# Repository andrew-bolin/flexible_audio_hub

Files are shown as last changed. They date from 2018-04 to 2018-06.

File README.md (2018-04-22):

# flexible_audio_hub

## The Challenge

My ears and speakers will last a lifetime (I hope), but home theatre audio standards do not. My old stereo amplifier works fine, why can't I get an HDMI upgrade module that gives it CEC (control via TV remote). If I buy a 5.1 channel amplifier, why do I have to throw it in the bin to upgrade to Atmos?

A modern AVR (Audio-Video Receiver) is a fantastic piece of technology, but they are available only in certain fixed configurations and are not easily modifiable.

## How Will We Alleviate The Problem?

1. A modular "hub" that allows incremental upgrades, e.g. an extra analog input, an extra two channels of amplification, or even another hub...
2. Compatibility with other open source projects in this field.
3. Ability to make use of readily available (cheap!) modules from China.
4. Ability to connect to home automation systems (e.g. limit the volume and turn off the subwoofer if someone's in bed, or play your wake-up alarm at rock concert levels throughout the house)

The modular system will be entirely open-source so that any interested person can make their own module to serve their unique needs (or for fun). Eventually I would like to see compatible modules available from multiple vendors (much like Raspberry Pi & Arduino add-ons).

## (Notes Working Towards) The Specification

[The Current Specification](SPECIFICATION.md) - very much a work in progress!

The first stage will be electrical & communications protocol only.

Currently, I am deciding on a connector - if anyone knows a connector that is a reasonable pitch (0.5 - 2.5mm), keyed, upwards-compatible with extra pins (e.g. a 16-pin plug can fit into a 20-pin socket), and **cheap**, please get in contact!

*Previously, I started a similar project using a backplane, because edge connectors are cheap, but the design I was using had the switching complexity by necessity in every module, was difficult to integrate into a chassis, and did not offer full flexibility for multiple simultaneous outputs. Now I will move that complexity to a "hub" board.*

Each module should (yes, it's optional) have an ID EEPROM & accept a few basic commands (Enable, select channel) via I2C. This can be achieved via a PCA9500 I/O expander or ATtiny, for example. Modules without the ID/Control interface will require more configuration effort and might waste a bit more power (the central hub will probably not have power switches per module).

The hub will be controlled by I2C, and a C++ library will be provided that will be usable via Arduino and Raspberry Pi. The hub will be able to be daisy-chained. 

----

These files are distributed under The TAPR Open Hardware License, version 1.0.  
See LICENSE.txt or https://www.tapr.org/ohl.html

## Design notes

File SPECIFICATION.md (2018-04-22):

# Flexible Audio Hub - Specification

## PRELIMINARY - FOR COMMENT - NOT FOR MANUFACTURE

# Hub Connector
Equivalent to [FreeDSP expansion connector](https://github.com/freeDSP/WIKI-AND-GENERAL-TOPICS/wiki/freeDSP-Guidelines).
16 pin (2x8) header, 2.54mm pitch.

## Hub-side

| Function | Pin | Pin | Function |
| ---: | :---: | :---: | --- |
| +12V |  1|2 | Gnd |
| I2S in |  3|4 | Gnd |
| I2S out|  5|6 | Gnd |
| bit clk|  7|8 | Gnd |
| LR clk |  9|10| Gnd |
| SDA | 11|12| Gnd |
| SCL | 13|14| Gnd |
| Mclk | 15|16| Gnd |

## Module-side

Out & in are swapped from hub side.

| Function | Pin | Pin | Function |
| ---: | :---: | :---: | --- |
| +12V |  1|2 | Gnd |
| **I2S out**|  3|4 | Gnd |
| **I2S in** |  5|6 | Gnd |
| bit clk|  7|8 | Gnd |
| LR clk |  9|10| Gnd |
| SDA | 11|12| Gnd |
| SCL | 13|14| Gnd |
| Mclk | 15|16| Gnd |

# Hub ID EEPROM

I2C Interface, address 0x50 (7 bit address) / 0xA0  (8 bit address).  
16 bit addressing. Any standard EEPROM chip should do the trick - CAT24Cxx, AT24Cxx, AT24CSxx, etc.

## Memory Map	 - Development version 1

Protocol / EEPROM uses odd version numbers for development, even numbers for production. Zero is not a valid version.
Strings are ASCII (maybe unicode later...).
This version needs only 1kbit of memory.

| Byte | Function | Detail |
| ---: | --- | --- |
| 0 | Magic Number | 0x46 'F' |
| 1 | Magic Number | 0x41 'A' |
| 2 | Magic Number | 0x48 'H' |
| 3 | Magic Number | 0x00 ''  |
| 4 | Bus Protocol Version | 0x01 |
| 5 | Module type | bitfield - in,dsp,out, etc |
| 6 | Number of audio channels in I2S data | only 0x02 for now |
| 7 | Number of selectable module channels | e.g. if we have multiple stereo ADCs |
| 8 | Power requirement | rated mA from 12V supply |
| 8-15 | -- Reserved -- | |
| 16-31| Module short name | 16 characters - model number or similar |
| 32-95| Module long name | 64 characters - e.g. "Quad Stereo Balanced Analog Input"|
| 96-127|Manufacturer | 32 characters |
|128-255| -- Reserved -- | |
|256+ | User Configuration (Module defined) ||

# Module Control

Modules can optionally be controlled by I2C commands.
Address 0x20 (7 bit address) / 0x40 (8 bit address), for compatibility with [PCA9500](https://www.nxp.com/docs/en/data-sheet/PCA9500.pdf). I2C Command is per PCA9500 output control (will add detail here later).

## Proposed Commands
* Select 0 (select an input/output/mode)
* Select 1
* Select 2
* Select 3
* Power
* Mute

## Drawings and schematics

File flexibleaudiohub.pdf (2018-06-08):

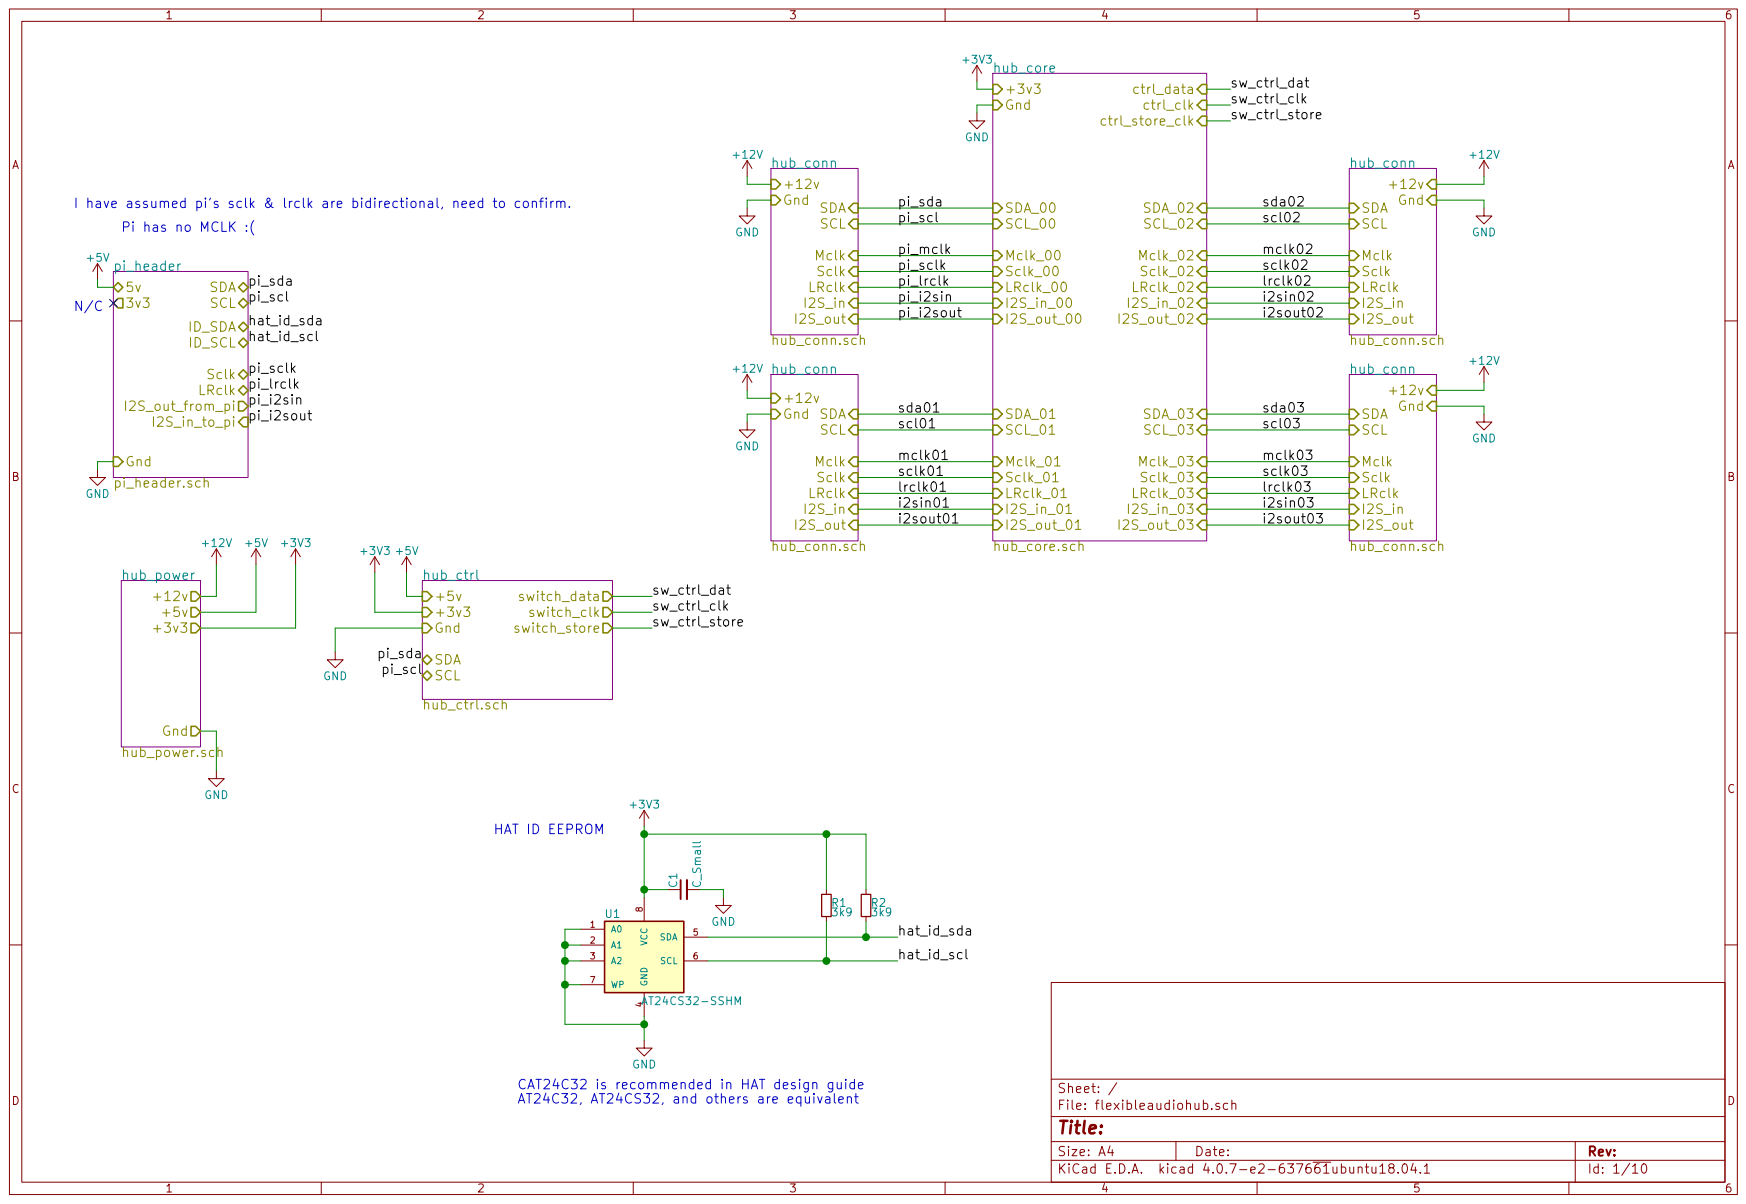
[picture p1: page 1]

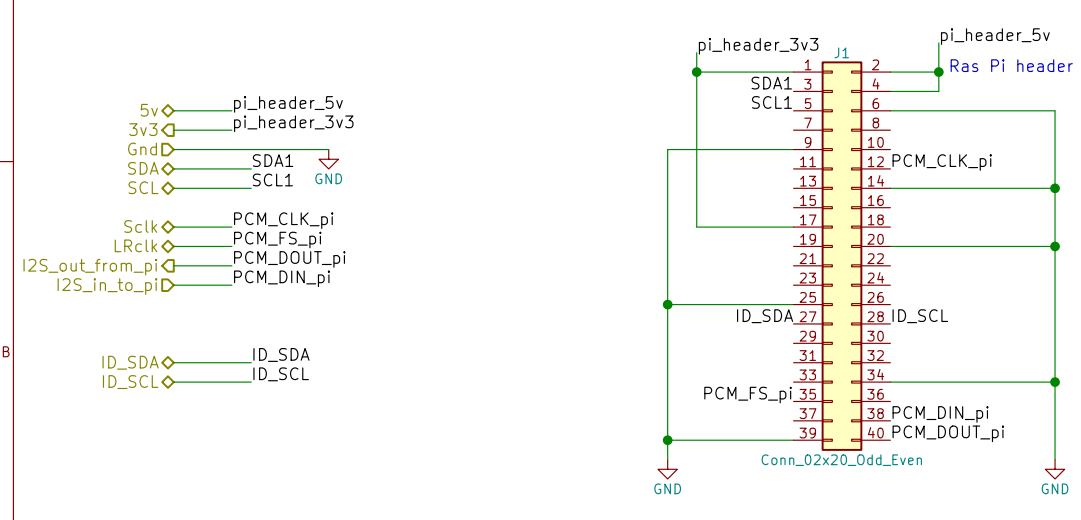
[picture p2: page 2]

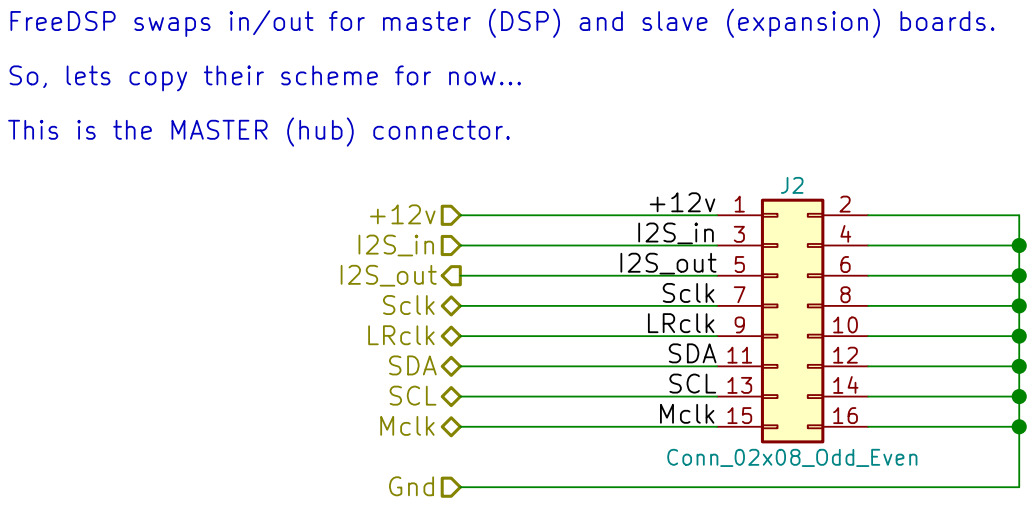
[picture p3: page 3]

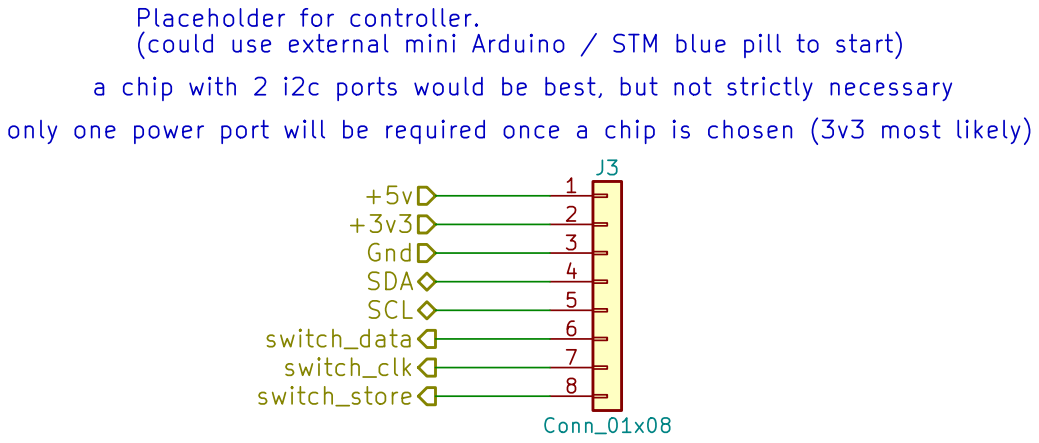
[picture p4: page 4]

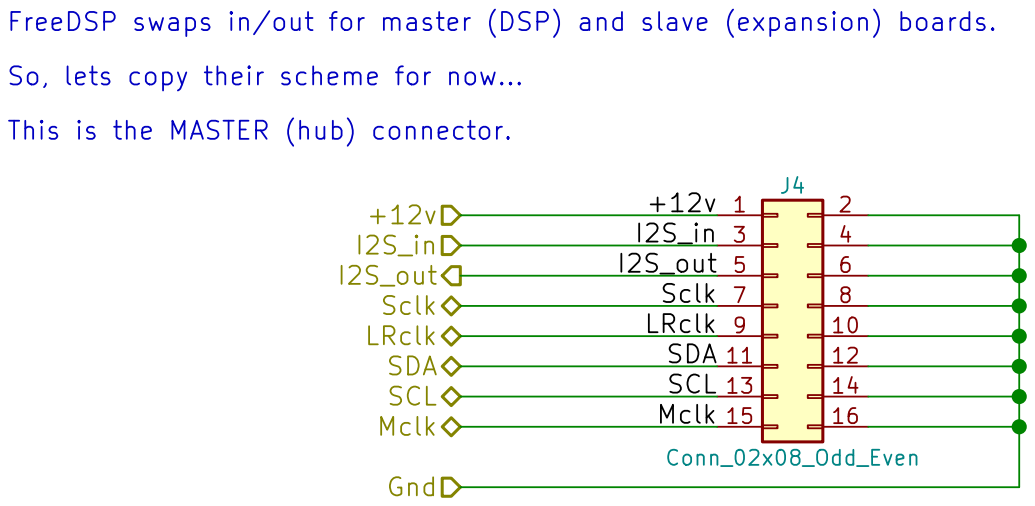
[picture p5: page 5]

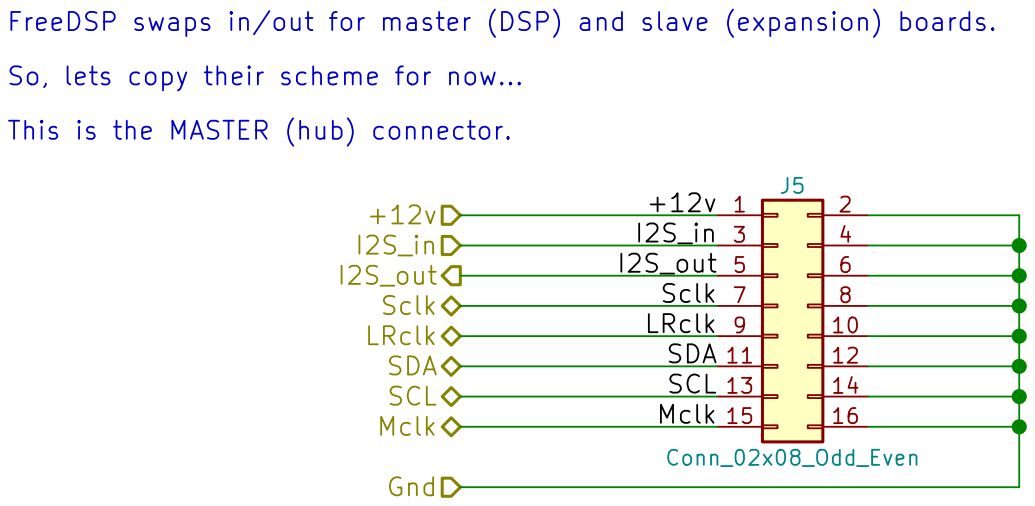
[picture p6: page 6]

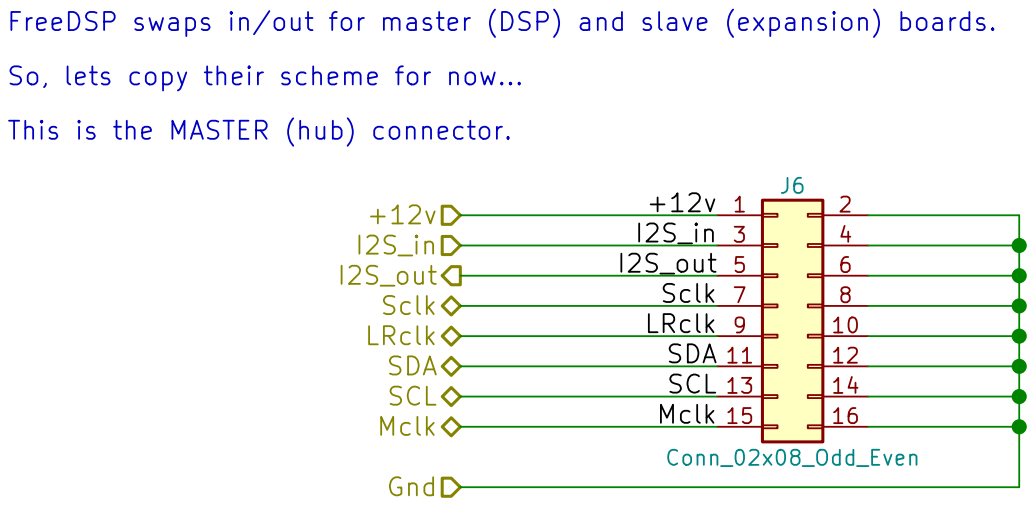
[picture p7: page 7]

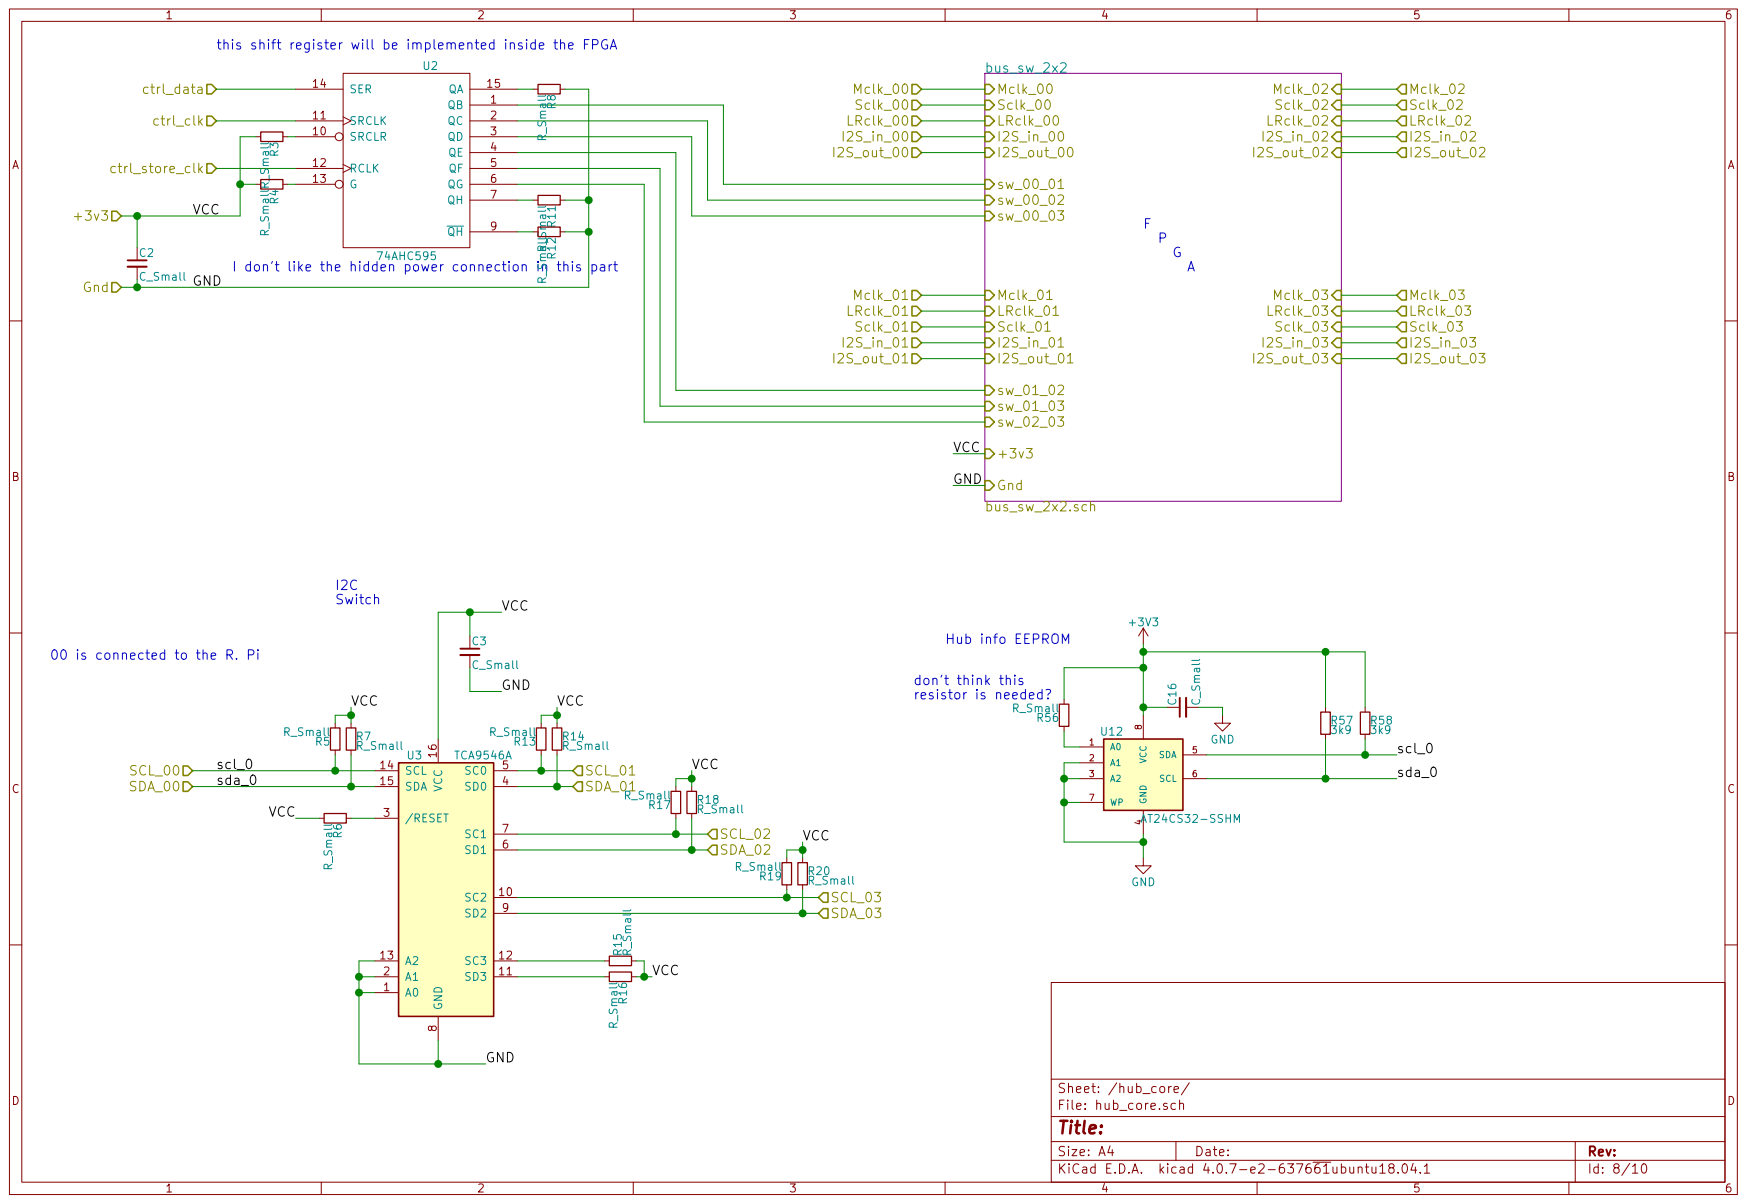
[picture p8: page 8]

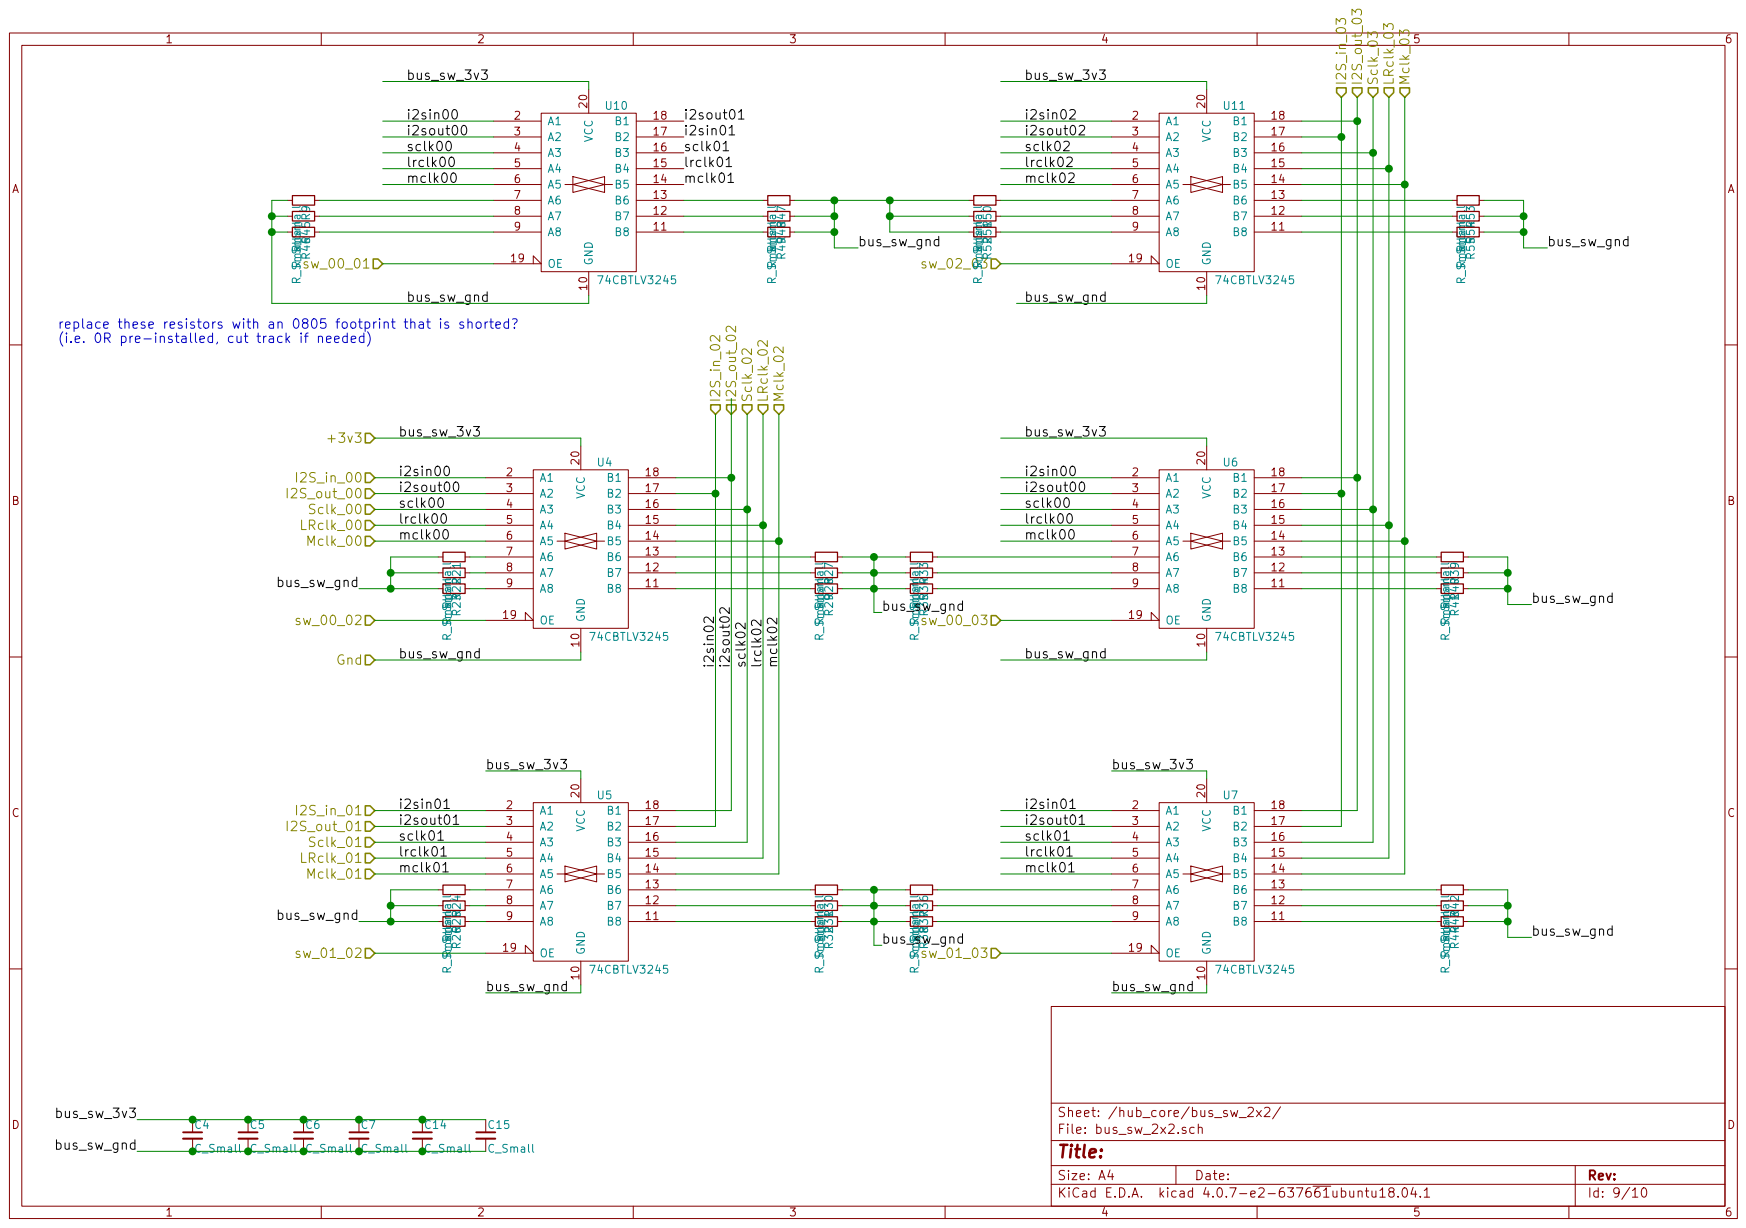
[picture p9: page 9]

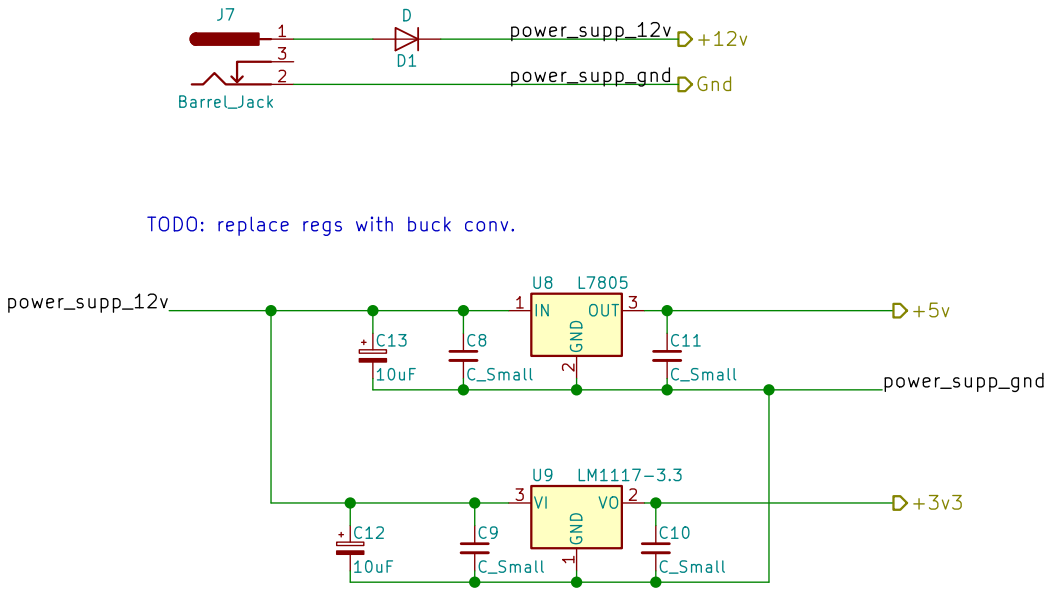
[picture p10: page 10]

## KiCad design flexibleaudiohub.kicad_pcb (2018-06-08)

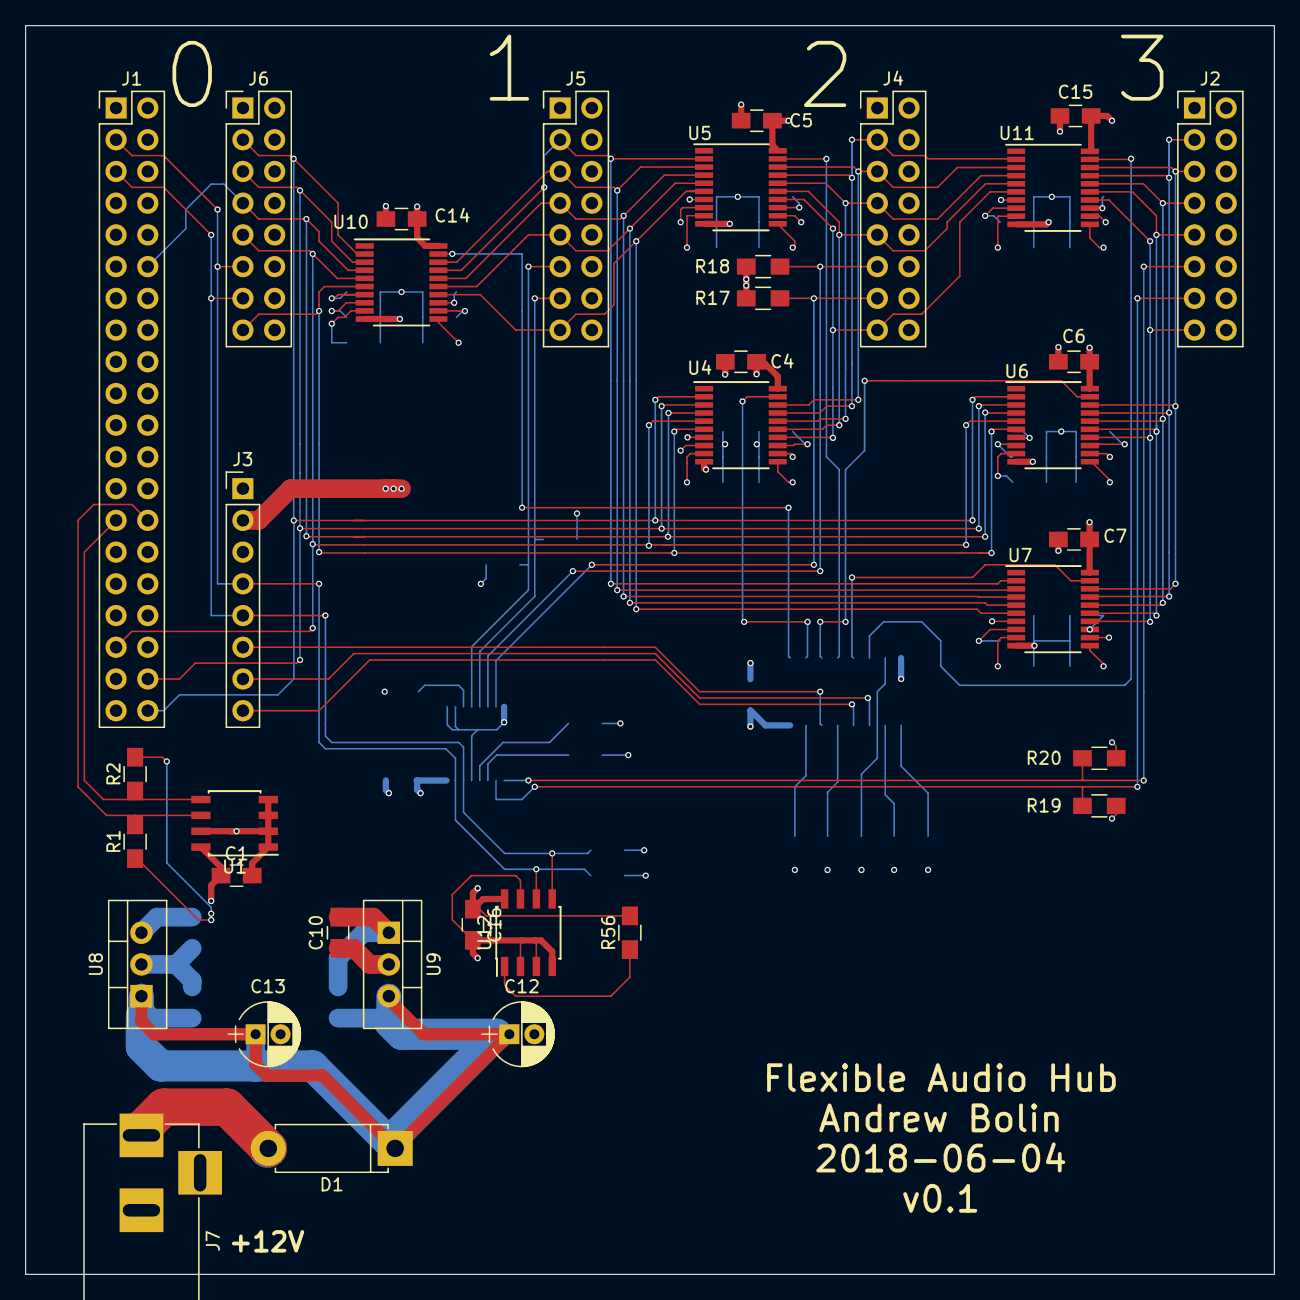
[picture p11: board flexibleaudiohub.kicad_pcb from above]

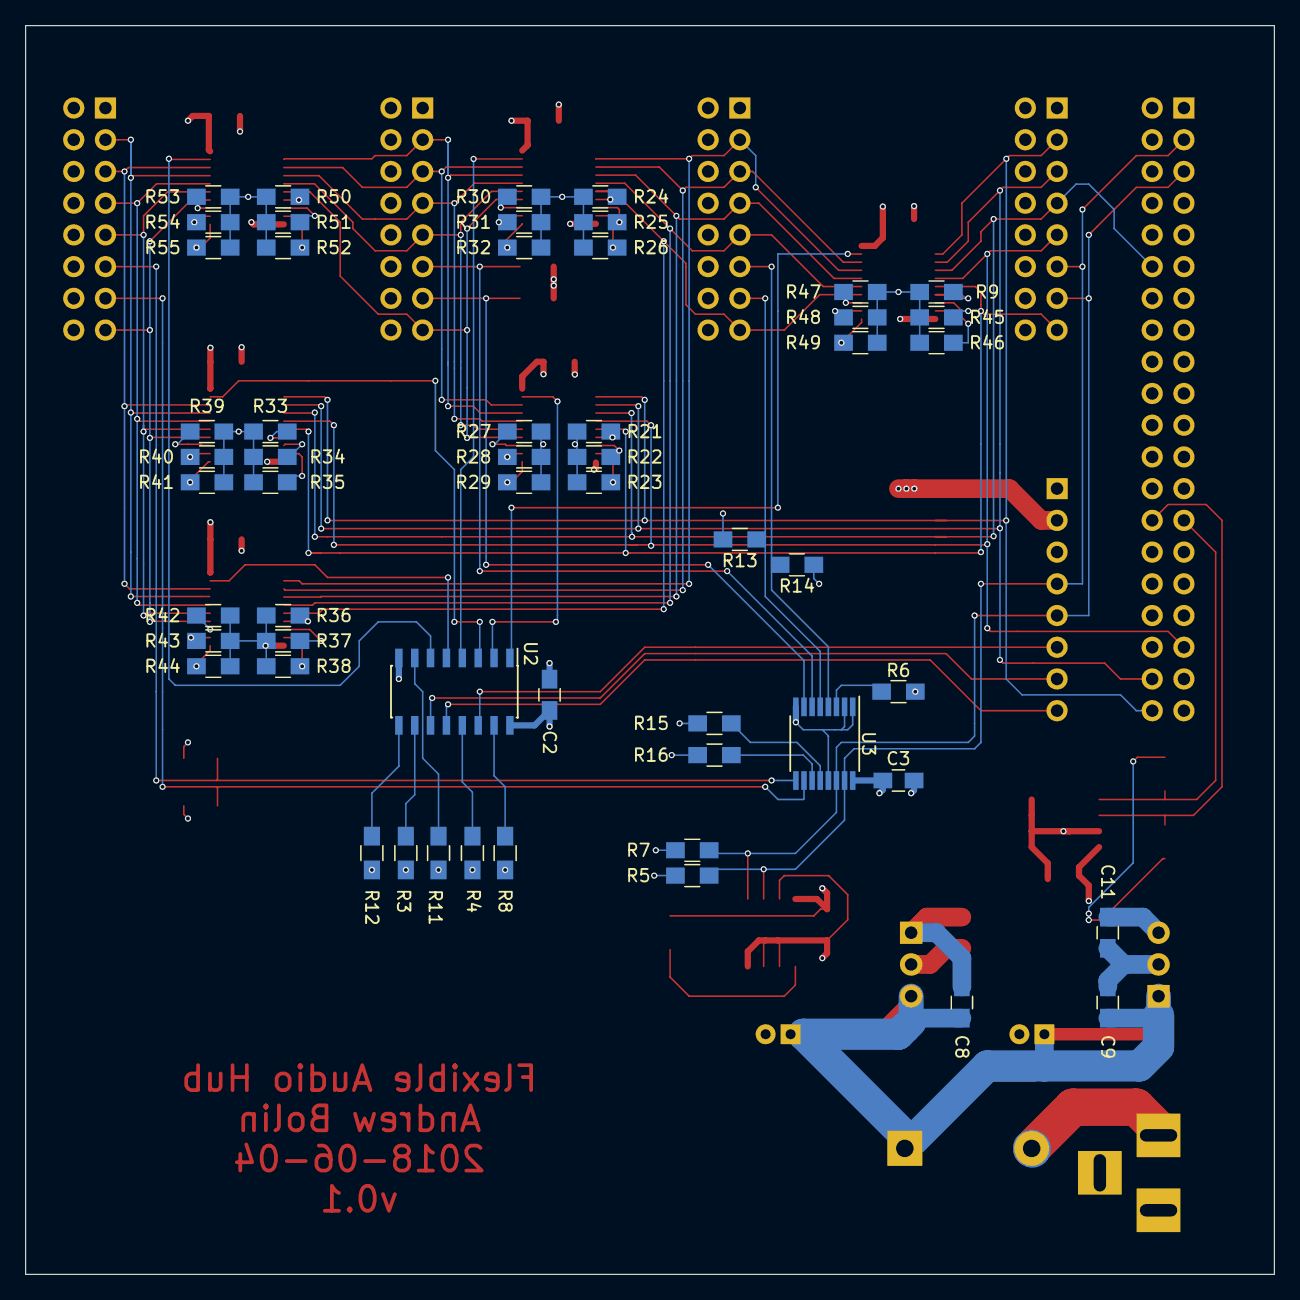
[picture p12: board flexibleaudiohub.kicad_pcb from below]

Board: 4 copper layers, 100.0 x 100.0 mm, 91 parts (55 on the bottom side), 90 nets.

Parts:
C1, C2, C3, C4, C5, C6, C7, C8, C9, C10, C11, C14, C15, C16: C_Small; C_0805_HandSoldering
C12, C13: 10uF; CP_Radial_D5.0mm_P2.00mm
D1: D; D_5W_P10.16mm_Horizontal
J1: Conn_02x20_Odd_Even; Pin_Header_Straight_2x20_Pitch2.54mm
J2, J4, J5, J6: Conn_02x08_Odd_Even; Pin_Header_Straight_2x08_Pitch2.54mm
J3: Conn_01x08; Pin_Header_Straight_1x08_Pitch2.54mm
J7: Barrel_Jack; BARREL_JACK
R1, R2: 3k9; R_0805_HandSoldering
R3, R4, R5, R6, R7, R8, R9, R11, R12, R13, R14, R15, R16, R17, R18, R19, R20, R21, R22, R23, R24, R25, R26, R27, R28, R29, R30, R31, R32, R33, R34, R35, R36, R37, R38, R39, R40, R41, R42, R43, R44, R45, R46, R47, R48, R49, R50, R51, R52, R53, R54, R55, R56: R_Small; R_0805_HandSoldering
U1, U12: AT24CS32-SSHM; SOIC-8_3.9x4.9mm_Pitch1.27mm
U2: 74AHC595; SOIC-16_3.9x9.9mm_Pitch1.27mm
U3: TCA9546A; TSSOP-16_4.4x5mm_Pitch0.65mm
U4, U5, U6, U7, U10, U11: 74CBTLV3245; TSSOP-20_4.4x6.5mm_Pitch0.65mm
U8: L7805; TO-220_Vertical
U9: LM1117-3.3; TO-220_Vertical

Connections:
+3V3: C1.1, C2.1, C3.1, C4.1, C5.1, C6.1, C7.1, C10.1, C14.1, C15.1, C16.1, J3.2, R1.1, R2.1, R3.2, R4.2, R5.2, R6.2, R7.1, R13.2, R14.1, R15.2, R16.1, R17.2, R18.1, R19.2, R20.1, R56.2, U1.8, U2.16, U3.16, U4.20, U5.20, U6.20, U7.20, U9.2, U10.20, U11.20, U12.8
+5V: C11.1, J1.2, J1.4, J3.1, U8.3
+12V: C8.1, C9.1, C12.1, C13.1, D1.1, J2.1, J4.1, J5.1, J6.1, U8.1, U9.3
/hat_id_scl: J1.28, R1.2, U1.6
/hat_id_sda: J1.27, R2.2, U1.5
/hub_core/bus_sw_2x2/sw_00_01: U2.1, U10.19
/hub_core/bus_sw_2x2/sw_00_02: U2.2, U4.19
/hub_core/bus_sw_2x2/sw_00_03: U2.3, U6.19
/hub_core/bus_sw_2x2/sw_01_02: U2.4, U5.19
/hub_core/bus_sw_2x2/sw_01_03: U2.5, U7.19
/hub_core/bus_sw_2x2/sw_02_03: U2.6, U11.19
/i2sin01: J5.3, U5.2, U7.2, U10.17
/i2sin02: J4.3, U4.17, U5.17, U11.2
/i2sin03: J2.3, U6.17, U7.17, U11.17
/i2sout01: J5.5, U5.3, U7.3, U10.18
/i2sout02: J4.5, U4.18, U5.18, U11.3
/i2sout03: J2.5, U6.18, U7.18, U11.18
/lrclk01: J5.9, U5.5, U7.5, U10.15
/lrclk02: J4.9, U4.15, U5.15, U11.5
/lrclk03: J2.9, U6.15, U7.15, U11.15
/mclk01: J5.15, U5.6, U7.6, U10.14
/mclk02: J4.15, U4.14, U5.14, U11.6
/mclk03: J2.15, U6.14, U7.14, U11.14
/pi_header/3v3: J1.1, J1.17
/pi_i2sin: J1.40, J6.3, U4.2, U6.2, U10.2
/pi_i2sout: J1.38, J6.5, U4.3, U6.3, U10.3
/pi_lrclk: J1.35, J6.9, U4.5, U6.5, U10.5
/pi_mclk: J6.15, U4.6, U6.6, U10.6
/pi_scl: J1.5, J3.5, J6.13, R5.1, U3.14, U12.5
/pi_sclk: J1.12, J6.7, U4.4, U6.4, U10.4
/pi_sda: J1.3, J3.4, J6.11, R7.2, U3.15, U12.6
/scl01: J5.13, R13.1, U3.5
/scl02: J4.13, R17.1, U3.7
/scl03: J2.13, R19.1, U3.10
/sclk01: J5.7, U5.4, U7.4, U10.16
/sclk02: J4.7, U4.16, U5.16, U11.4
/sclk03: J2.7, U6.16, U7.16, U11.16
/sda01: J5.11, R14.2, U3.4
/sda02: J4.11, R18.2, U3.6
/sda03: J2.11, R20.2, U3.9
/sw_ctrl_clk: J3.7, U2.11
/sw_ctrl_dat: J3.6, U2.14
/sw_ctrl_store: J3.8, U2.12
GND: C1.2, C2.2, C3.2, C4.2, C5.2, C6.2, C7.2, C8.2, C9.2, C10.2, C11.2, C12.2, C13.2, C14.2, C15.2, C16.2, J1.6, J1.9, J1.14, J1.20, J1.25, J1.34, J1.39, J2.2, J2.4, J2.6, J2.8, J2.10, J2.12, J2.14, J2.16, J3.3, J4.2, J4.4, J4.6, J4.8, J4.10, J4.12, J4.14, J4.16, J5.2, J5.4, J5.6, J5.8, J5.10, J5.12, J5.14, J5.16, J6.2, J6.4, J6.6, J6.8, J6.10, J6.12, J6.14, J6.16, J7.2, R8.1, R9.2, R11.1, R12.1, R21.2, R22.2, R23.2, R24.2, R25.2, R26.2, R27.1, R28.1, R29.1, R30.1, R31.1, R32.1, R33.2, R34.2, R35.2, R36.2, R37.2, R38.2, R39.1, R40.1, R41.1, R42.1, R43.1, R44.1, R45.2, R46.2, R47.1, R48.1, R49.1, R50.2, R51.2, R52.2, R53.1, R54.1, R55.1, U1.1, U1.2, U1.3, U1.4, U1.7, U2.8, U3.1, U3.2, U3.8, U3.13, U4.10, U5.10, U6.10, U7.10, U8.2, U9.1, U10.10, U11.10, U12.2, U12.3, U12.4, U12.7
unnamed: D1.2, J7.1
unnamed: R3.1, U2.10
unnamed: R4.1, U2.13
unnamed: R6.1, U3.3
unnamed: R8.2, U2.15
unnamed: R9.1, U10.7
unnamed: R11.2, U2.7
unnamed: R12.2, U2.9
unnamed: R15.1, U3.12
unnamed: R16.2, U3.11
unnamed: R21.1, U4.7
unnamed: R22.1, U4.8
unnamed: R23.1, U4.9
unnamed: R24.1, U5.7
unnamed: R25.1, U5.8
unnamed: R26.1, U5.9
unnamed: R27.2, U4.13
unnamed: R28.2, U4.12
unnamed: R29.2, U4.11
unnamed: R30.2, U5.13
unnamed: R31.2, U5.12
unnamed: R32.2, U5.11
unnamed: R33.1, U6.7
unnamed: R34.1, U6.8
unnamed: R35.1, U6.9
unnamed: R36.1, U7.7
unnamed: R37.1, U7.8
unnamed: R38.1, U7.9
unnamed: R39.2, U6.13
unnamed: R40.2, U6.12
unnamed: R41.2, U6.11
unnamed: R42.2, U7.13
unnamed: R43.2, U7.12
unnamed: R44.2, U7.11
unnamed: R45.1, U10.8
unnamed: R46.1, U10.9
unnamed: R47.2, U10.13
unnamed: R48.2, U10.12
unnamed: R49.2, U10.11
unnamed: R50.1, U11.7
unnamed: R51.1, U11.8
unnamed: R52.1, U11.9
unnamed: R53.2, U11.13
unnamed: R54.2, U11.12
unnamed: R55.2, U11.11
unnamed: R56.1, U12.1

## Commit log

2018-04-19 pcb skeleton (in progress)
    [flexibleaudiohub.kicad_pcb, flexibleaudiohub.sch, hub_conn.sch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]
2018-04-22 preliminary schematic using discrete logic chips
    [bus_sw_2x2.sch, flexibleaudiohub.sch, hub_conn.sch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]
2018-04-22 PDF schematic
2018-06-08 finished layout
    [bus_sw_2x2.sch, flexibleaudiohub.kicad_pcb, flexibleaudiohub.sch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]
